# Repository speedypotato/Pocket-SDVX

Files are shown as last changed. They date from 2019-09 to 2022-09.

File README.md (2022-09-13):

# Pocket-SDVX
A mini controller for games such as Sound Voltex, USC, KShoot, osu 4k, etc.  Based off of mon's Pocket Voltex and Cammy's pocketvtx!

Although I won't be selling this particular design anymore, I have plans to sell other miniature controller designs soon.  Join the discord for discussion and support! https://discord.gg/MmuKd73XbY . I also now have a storefront! https://www.speedylabs.us/

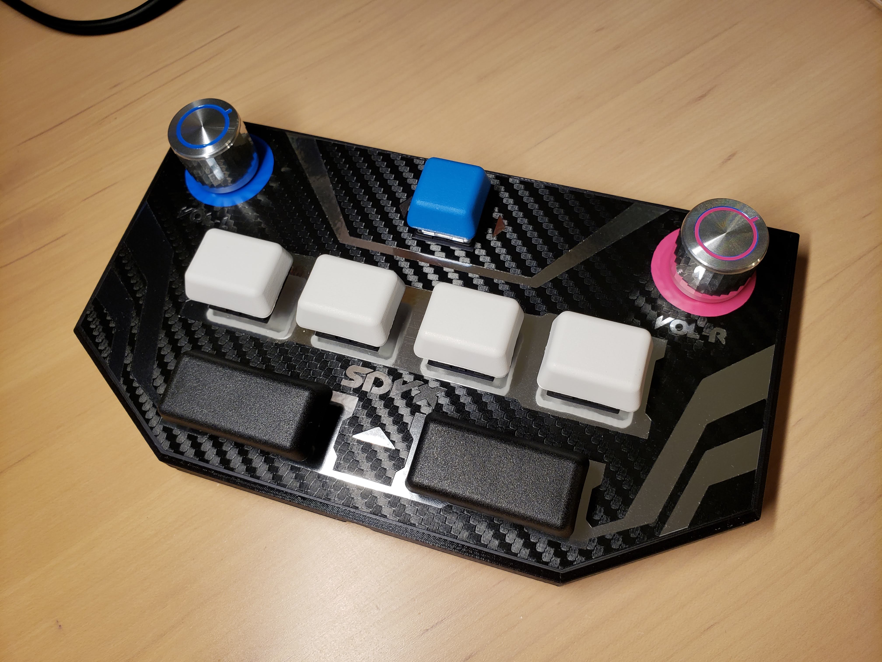
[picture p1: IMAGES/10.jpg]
Pocket SDVX 14


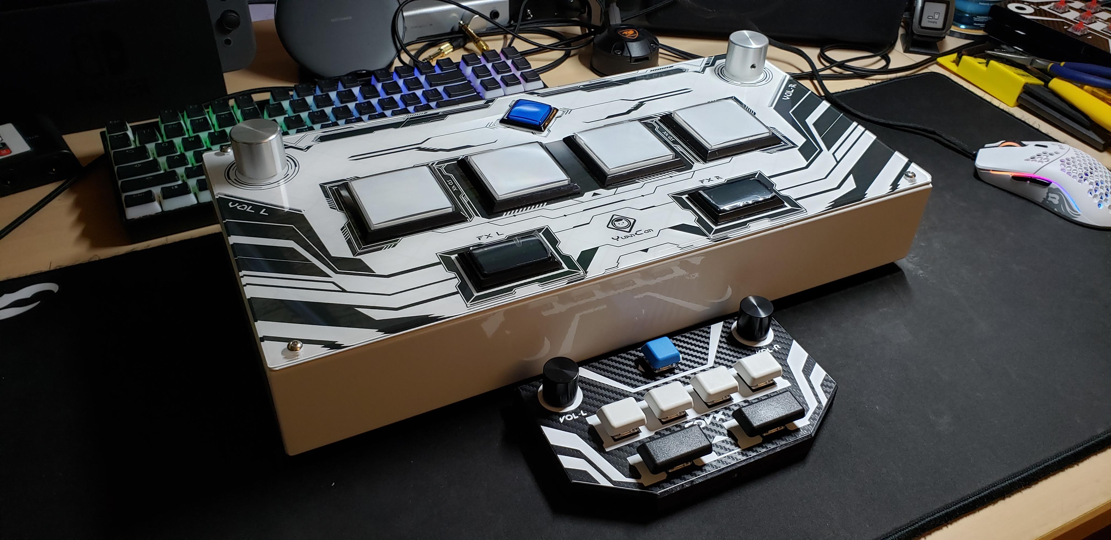
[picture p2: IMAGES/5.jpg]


## Features
- Super small - About 7" x 4" and a little over 1/2" high (About 1-1/2" including knobs)
- 7 Gateron Red Keyswitches (Start, BT-A, BT-B, BT-C, BT-D, FX-L, FX-R)
- Reactive & HID LEDs
- PBT G20 Keycaps
- Quality Bourns Encoders (VOL-L, VOL-R)
- Solid Aluminum Black 20mm Knobs
- Vinyl Skinned Top & Bottom
- 6 Rubber Feet
- Single Screw Back Panel
- Arduino Pro Micro based
- Acts as a gamepad or keyboard/mouse.  While plugging in, hold BTN-A for 3-4s for gamepad mode.  Hold BTN-B instead for keyboard/mouse mode.
- USB-C Input

## Video Guide
- A really low-quality video guide series I made at 4:00am: https://www.youtube.com/playlist?list=PLSlCMOwxujV7-DYrM4eC2Sb4_rMR5udEE .
  - Perhaps it will be useful to some of you.

## Parts Required:
- 1x 3D Printed Case (1.2mm walls, top, bottom layers; 20-25% infill minimum)
- 1x 3D Printed Cover
- 1x layer1 Vinyl Skin [width is ~169mm (scale the skin proportionally)]
- 1x layer2 Vinyl Skin [width is ~169mm (scale the skin proportionally)]
- 1x cover Vinyl Skin [width is ~165mm (scale the skin proportionally)]
- 7x Gateron Red Keyswitches (or other similar MX-style switch)
- 2x Bourns PEC16-2015F-N0024 Encoders
- 1x 1x1 G20 Keycap
- 4x 1x1.25 G20 Keycap
- 2x 1x2 G20 Keycap
- 2x 20mm Diameter Solid Aluminum Knobs (17-22mm height, 6mm inner diameter hole)
- 1x Arduino Pro Micro
- 6x Rubber Feet (0.8-1cm in diameter)
- 1x Micro USB Male to USB C Female (27cm length)
- 1x M3x5 Screw
- Cat5e Cable (~2 feet, strip it open and take a twist of wire)
- Hot Glue
- Solder
- USB C cable (preferably one with deep insertion)

## LED Parts Required:
- 7x 2x3x4mm Square LEDs (choose your desired colors)
- 7x Resistors (High brightness 100Ohm, Medium brightness 220Ohm)

## Recommended Tools/Etc.
- Temperature Controlled Soldering Iron
- Hot Glue Gun
- Needle Nose Pliers
- Wire Cutter/Stripper
- Phillips Screwdriver (if you use a phillips head M3 screw)
- Allen Key (for knobs' grubscrew, M3 screw if you have a hex head)
- Rubbing/Isopropyl Alcohol
- Microfiber Cloth (for cleaning w/ alcohol)
- Eye Protection + Safety Mask

## General Assembly Instructions
- 3D print case and cover.
- Cut vinyls: layer1, layer2, cover_v2.
- Weed vinyls(remove excess).
- Clean face with rubbing/isopropyl alcohol and apply skin using transfer tape.  Apply layer1, then layer2.  Then apply cover.
  - Note: Shine a flashlight on the case's corner to more easily see where to line up the skin.  I make my skins every so slightly smaller than the actual face for more leeway.  The skin's width is ~169mm (scale the skin proportionally).
  - Note 2: Apply to the best of your ability, with even spacing along all sides.  The skin's width is ~165mm (scale the skin proportionally).
- Insert Gateron switches and secure each corner of the switch with hot glue on the inside.  See video Part 1 for details.
- Using a soldering iron, tin all contacts on the Gateron switches.
- Wire up all the common/ground for the switches and the encoders.  See video Part 2 for details.
- Wire up all the switches and encoders with their own individual wire.
- Solder all the wires to the board.  See video Part 3 for details.
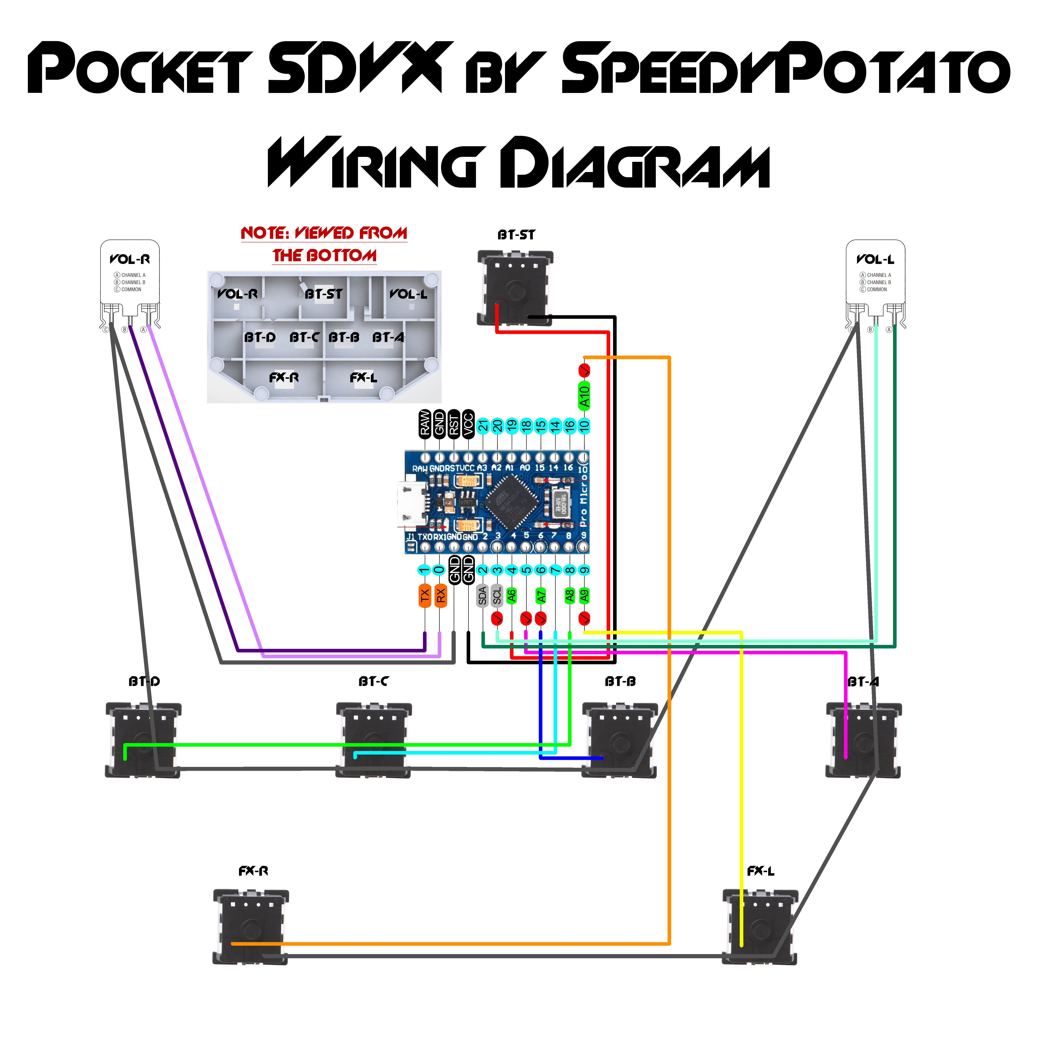
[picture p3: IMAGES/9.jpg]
Pocket SDVX Wiring Diagram
  
  - Arduino Pro Micro Pinout
    - VOL-L A 2
    - VOL-L B 3
    - VOL_R A 0 (RXI)
    - VOL_R B 1 (TXO)
    - BT_ST   4
    - BT_A    5
    - BT_B    6
    - BT_C    7
    - BT_D    8
    - FX_L    9
    - FX_R    10
- Plug in your arduino and flash firmware.  See video Part 4 for details.  Note: If you are running into the "Using OLD HID" error, try enabling verbose compilation output under File > Preferences > Show Verbose Output during [compilation] and uploading again.  For some reason, this fixes it for me most of the time.
- BOOT IN KEYBOARD MODE(Hold the second button from the left for 3-4s while plugging it in).  TEST to make sure everything works.  See video Part 5 for details.
- Plug in micro usb to USB-C adapter cable into the arduino.  Slide arduino into its slot and route the USB-C cable.  See video Part 6 for details.
- Push encoders through their holes.  Mount with washer and nut.
- Bend metal encoder mounting tabs 45 degrees outward.  Additionally, bend one of the protrusions slightly inward so it doesn't collide with the micro usb cable.
- Do some cable management.  Carefully flatten the cables.
- Hot glue USB-C port.
- Slide in the cover and secure with M3x5 screw.  PLEASE be careful, as you are threading into plastic and thus the hole is easily strippable.  See video Part 7 for details.
- Wipe circles on the bottom with rubbing/isopropyl alcohol.  Apply adhesive rubber feet.
- Mount keycaps.  See video Part 8 for details.
- Mount knobs.  Use the arduino pin headers as a spacer on each side so the knobs are the same height and don't rub on the encoder nub.
- Flash firmware and setup your desired game.  See "Pocket SDVX Guide - Flash Firmware & Game Setup" for details.
  - Arduino IDE: https://www.arduino.cc/en/main/software
  - KONAMI SPOOF NO LONGER NEEDED - JUST SELECT "ARDUINO LEONARDO"

## HID LED Assembly Instructions
- Take off keycaps.
- Insert LED through switch.
- Solder negative(shorter) leg to the switch's leg that connects to ground/common.  Clip LED shorter if needed.
- Solder resistor(100 or 220 Ohm depending on desired brightness) to positive(longer) leg.  Clip LED & resistor shorter if needed.
- Solder other end of resistor to a wire.  The other end of the wire will be soldered to the Arduino Pro Micro.
  - Arduino Pro Micro Pinout for LEDs
    - BT_ST_LED 16
    - BT_A_LED  14
    - BT_B_LED  15
    - BT_C_LED  18 (A0)
    - BT_D_LED  19 (A1)
    - FX_L_LED  20 (A2)
    - FX_R_LED  21 (A3)
- Plug in your arduino and flash firmware if it needs to be updated.
- Flatten cables and close cover.
### Done.  Enjoy!!

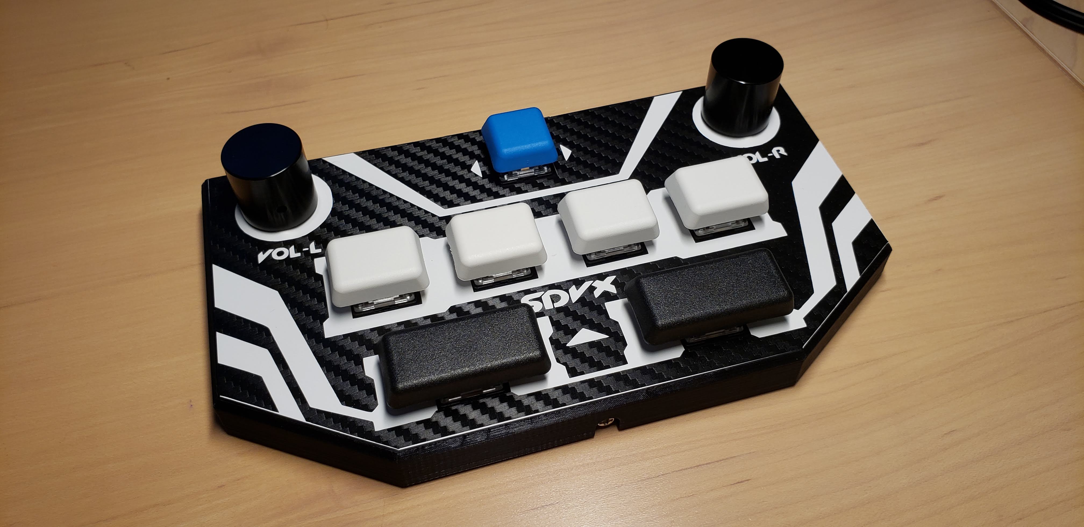
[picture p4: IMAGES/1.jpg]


## Links I used to make the first batch of 10
NOTE: Links dead?  See /IMAGES/screenshots/ for an example of what you are looking for!
- Gateron Red Keyswitches: https://kbdfans.com/collections/gateron-swithes/products/gateron-swtich-3pin-or-5pin?variant=35765199373
- Bourns PEC16-2015F-N0024 Encoders: https://www.mouser.com/ProductDetail/Bourns/PEC16-2015F-N0024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
- 1x1 G20 Keycap (BCT): https://pimpmykeyboard.com/g20-1-space-pack-of-10/
- 1x1.25 G20 Keycap (WAN): https://pimpmykeyboard.com/g20-1-25-space-pack-of-4/
- 1x2 G20 Keycap (NEM): https://pimpmykeyboard.com/g20-2-space-pack-of-4/
- 20mm Diameter Solid Aluminum Knobs: https://www.aliexpress.com/item/32912465745.html?spm=a2g0o.cart.0.0.43bd3c00dwdyAf&mp=1
- Arduino Pro Micro (WARNING: CONTAINS 10): https://www.aliexpress.com/item/4000045084392.html
- Rubber Feet: https://www.ebay.com/itm/50PCS-Rubber-Feet-Clear-Semicircle-Bumpers-Door-Silicone-Buffer-Pad-Furniture/152925672374
- Micro USB Male to USB C Female: https://www.aliexpress.com/item/32983342667.html
- M3x5 Screw: https://www.ebay.com/itm/20X-M3-3-80mm-Round-Pan-Head-Phillips-Screws-304-Stainless-Steel-Machine-Screws/302237442873
- USB C cable (WARNING: CONTAINS 10): https://www.aliexpress.com/item/33032210292.html

## Links I used for LEDs
NOTE: Links dead?  See /IMAGES/screenshots/ for an example of what you are looking for!
- 2x3x4mm LEDs: https://www.aliexpress.com/item/4000463652201.html
- 100Ohm Resistors: https://www.ebay.com/itm/100PCS-1-4W-0-25W-Metal-Film-Resistor-1-Full-Range-of-Values-0%CE%A9-to-10M%CE%A9/252838503547

## Alternate Parts to Consider
- DSA profile keycaps might be a good alternative to G20 if G20 is too expensive or hard to get.
- 20mm knobs can be picked up for much cheaper if you opt for ones that are not all aluminum.
- Can't get Bourns encoders?  Sorry, I have yet to find a good alternative.
- Vinyl skin alternative?  Print out layer2.png on paper, cut it out, and glue it on.  Can also try laminating with packing tape for more durability.
- Cherry MX O-Ring Dampers can be used for a quieter and softer bottom-out.  I had to put 2 on FX-L and FX-R each for dampening to work.  The rest of the keycaps have 1 O-Ring.

## Miscellaneous Info
- The fancy looking knobs I used for Pocket SDVX #14: https://www.amazon.com/gp/product/B07PQ5H6MF/
- I recommend printing the case in a solid dark color so that the pro micro LED doesn't shine through.  Then print the cover in a transparent/white color so that the pro micro LED shines through on the bottom, acting as a neat little power LED.
- If the rubber feet aren't doing their job, they're probably dusty.  Wipe them down with a little bit of rubbing alcohol.
- Encoders have an initial break-in period.  If they are stiff, rotate them for a few minutes to break them in.
- This work is licensed under a Creative Commons Attribution-NonCommercial-ShareAlike 4.0 International License.
Creative Commons

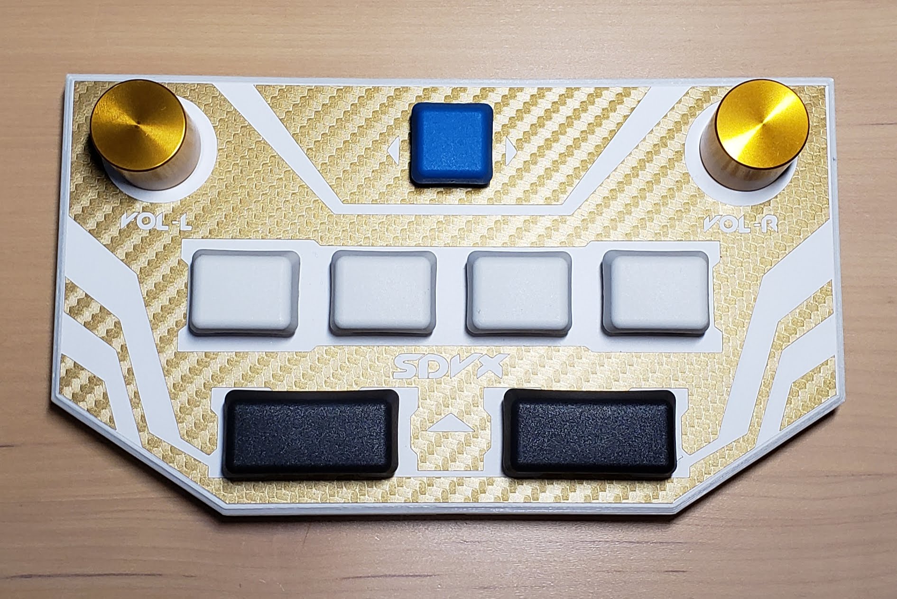
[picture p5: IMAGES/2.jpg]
Gold Pocket SDVX


## Thanks To
- Cammy for helping me build my first minicon.  The Pocket SDVX uses a slightly modified version of his firmware.
- Everyone in the Cons & Stuff Discord channel.
- mon for his initial development of the Pocket Voltex.
- The 10 people who purchased my first exclusive batch of Pocket SDVXs!  Thanks to you guys, I can get a full-size controller as well!
- CrazyRedMachine for HID stuff

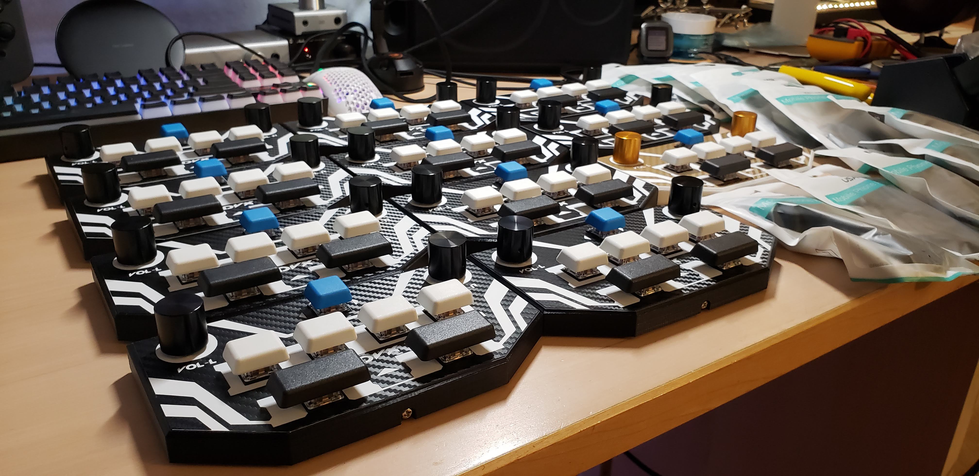
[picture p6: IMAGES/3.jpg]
10 Pocket SDVX


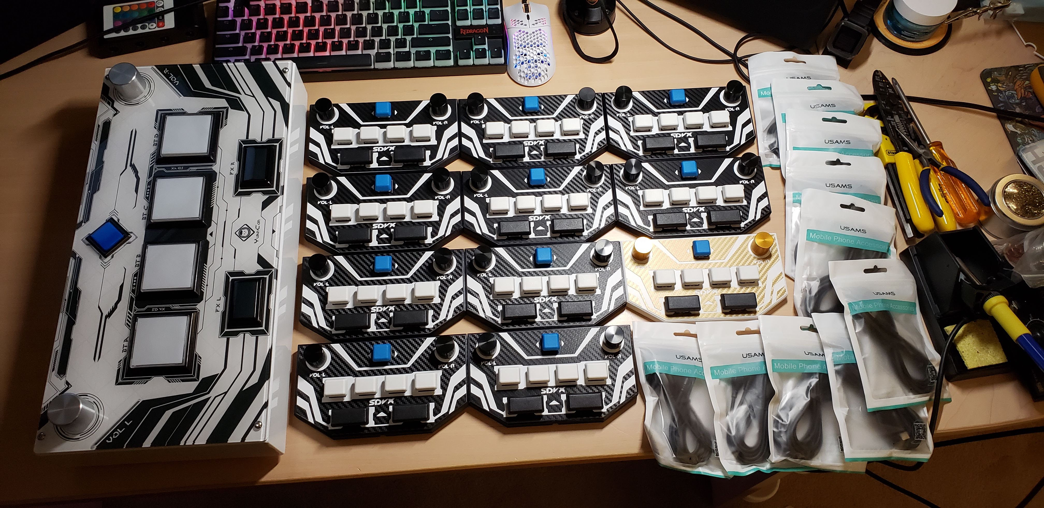
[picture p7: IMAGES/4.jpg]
10 Pocket SDVX 2


## Links to other GitHubs
- https://github.com/camprevail/pocketvtx
- https://github.com/mon/PocketVoltex

## Possible To-Do List
- M3 Nut hole on cover
- Increase spacing between BTN and FX
- Tweak vinyl skin aesthetic button size cutouts
- Consider new way to secure back panel

## Finished Items from the To-Do List
- Konami Spoof compatible
- HID LEDs [See YouTube guide]
- LED lights [See YouTube guide]
- Actually make a cover vinyl that fits right [use cover_v2.png]

## More Pictures
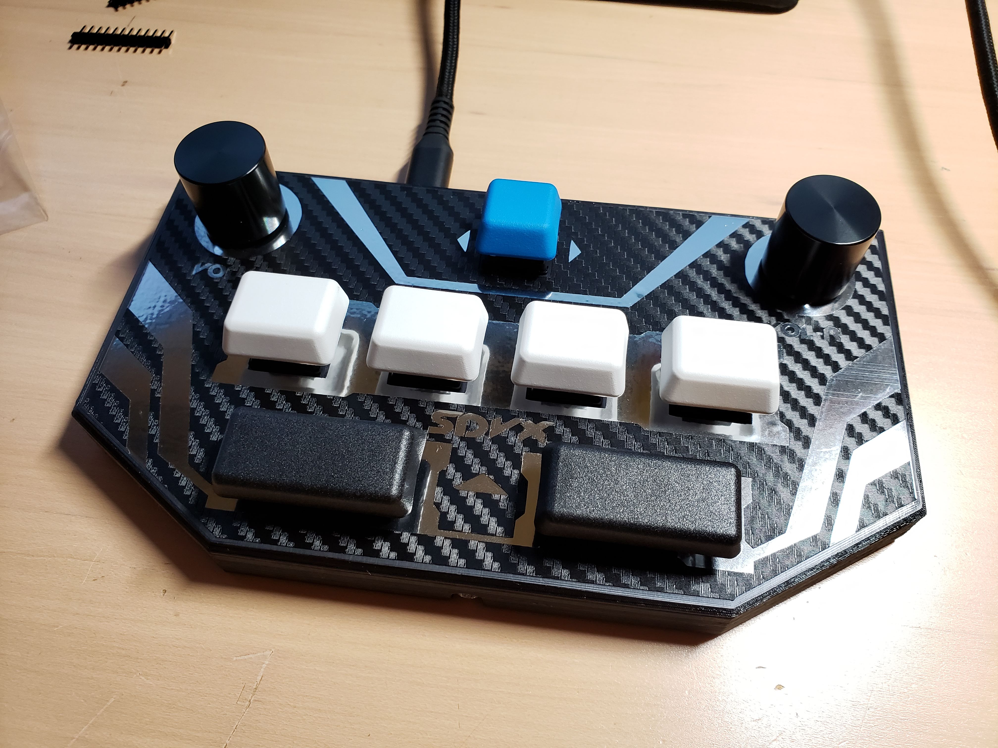
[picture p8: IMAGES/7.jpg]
Pocket SDVX 13


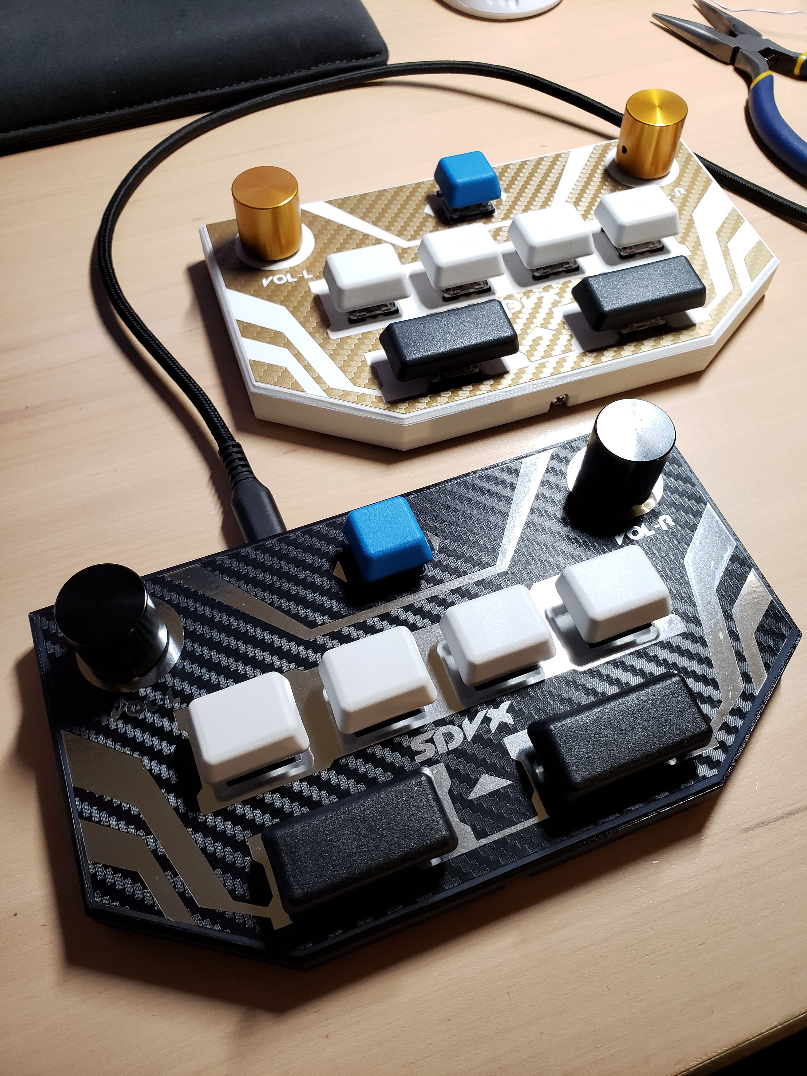
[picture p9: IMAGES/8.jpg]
Pocket SDVX 11 and 13


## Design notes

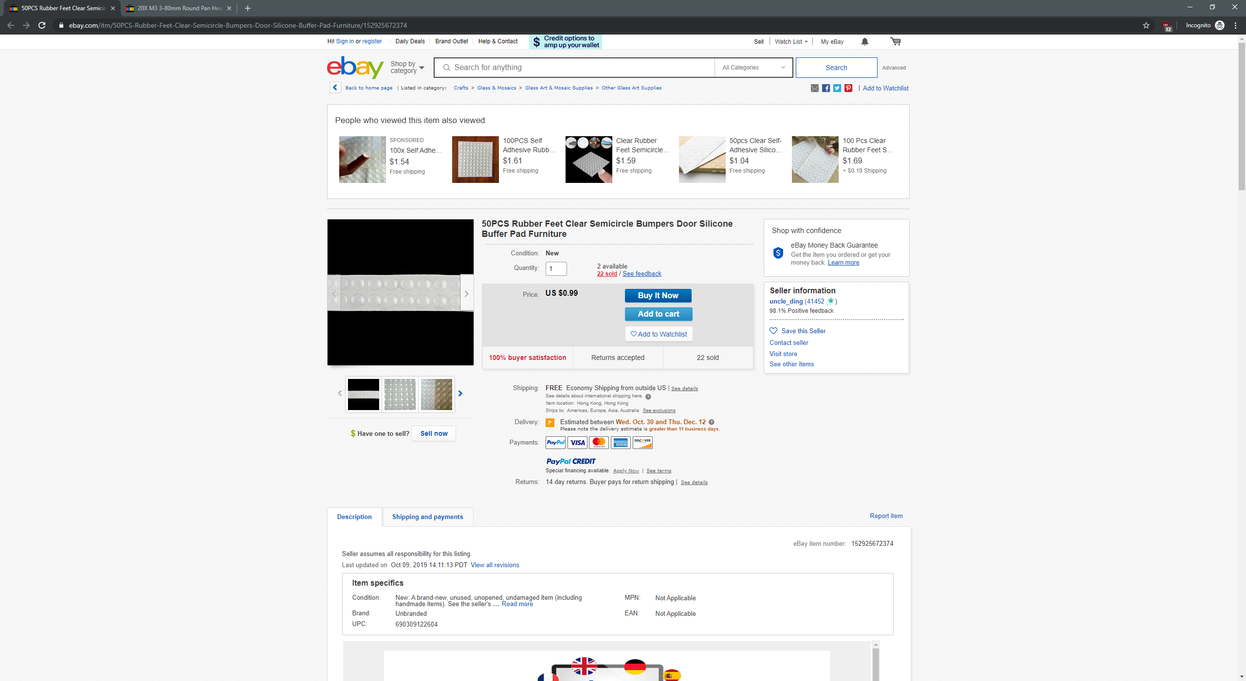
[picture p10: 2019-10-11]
IMAGES/screenshots/feet.png

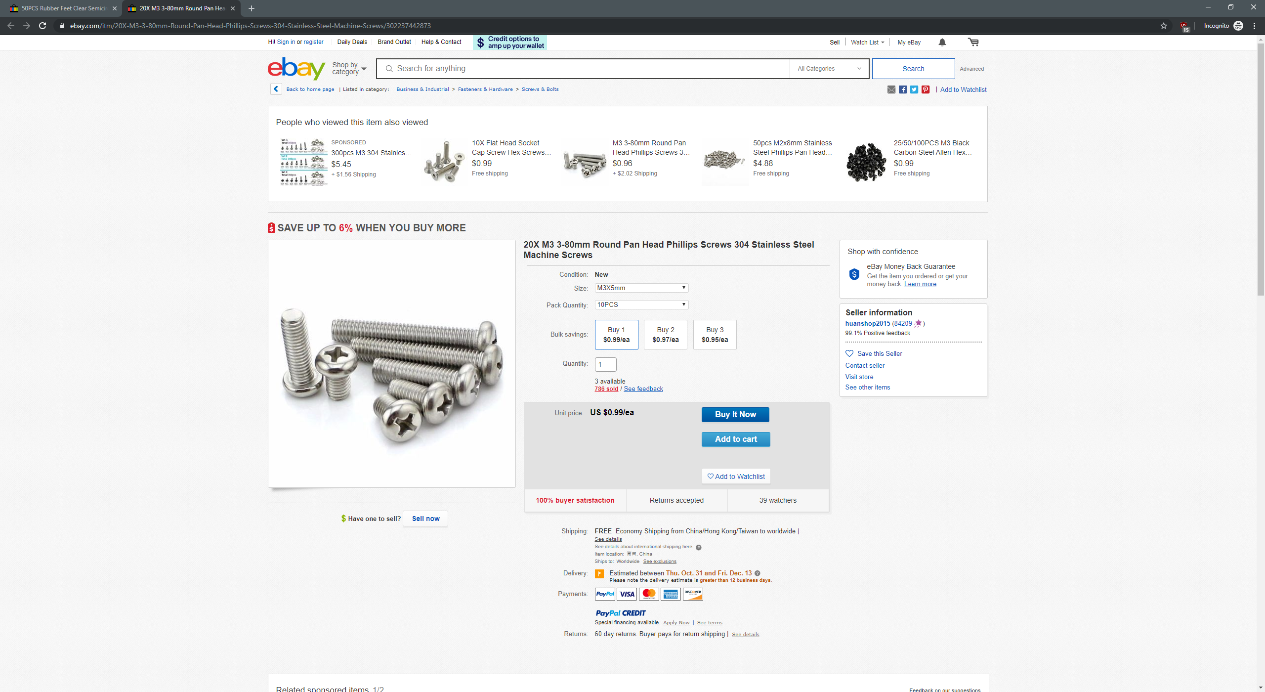
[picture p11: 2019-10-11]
IMAGES/screenshots/screw.png

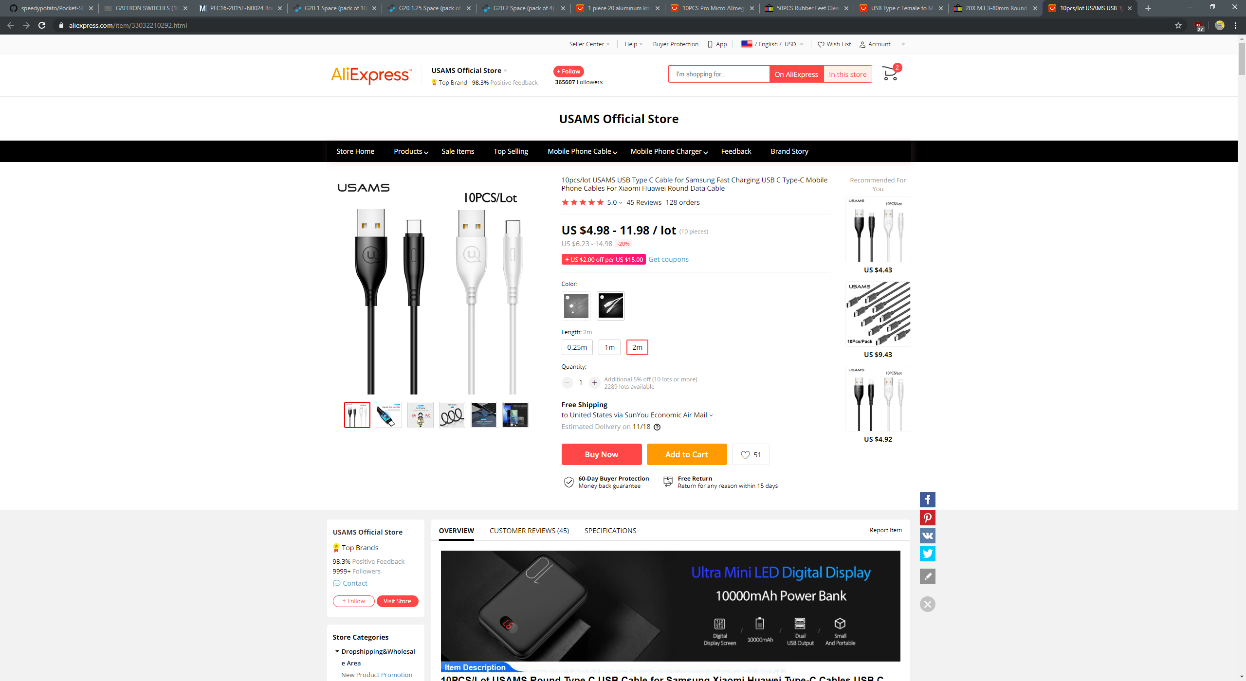
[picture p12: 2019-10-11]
IMAGES/screenshots/usbccable.png

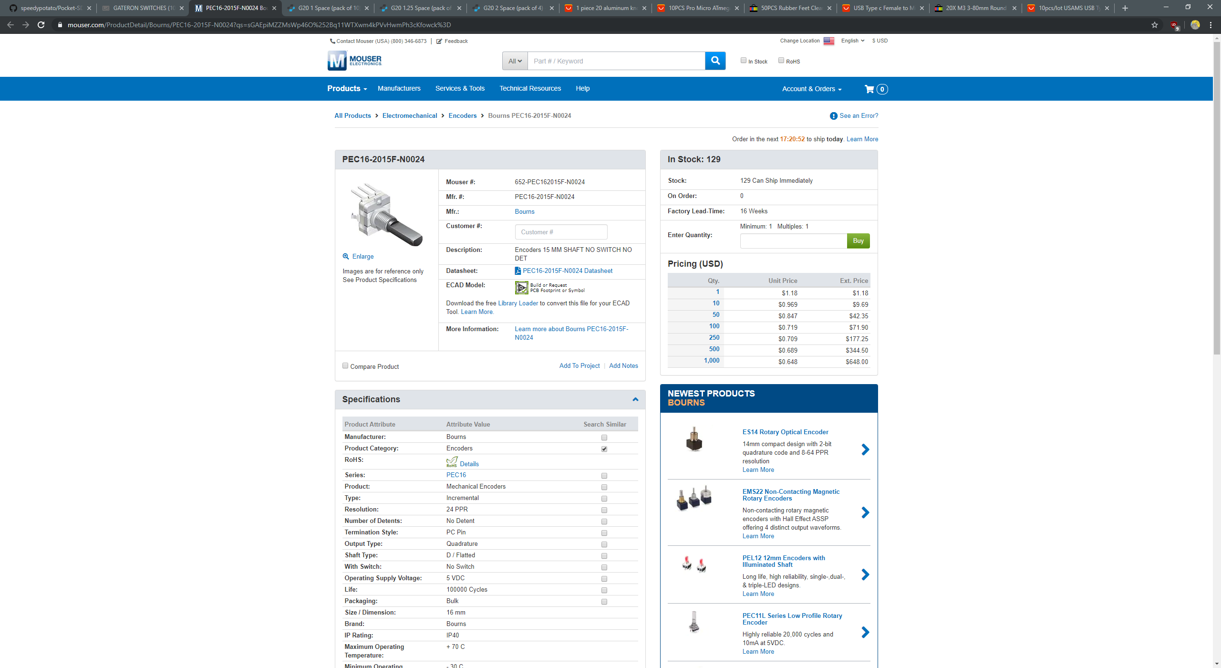
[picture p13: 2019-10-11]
IMAGES/screenshots/encoder.png

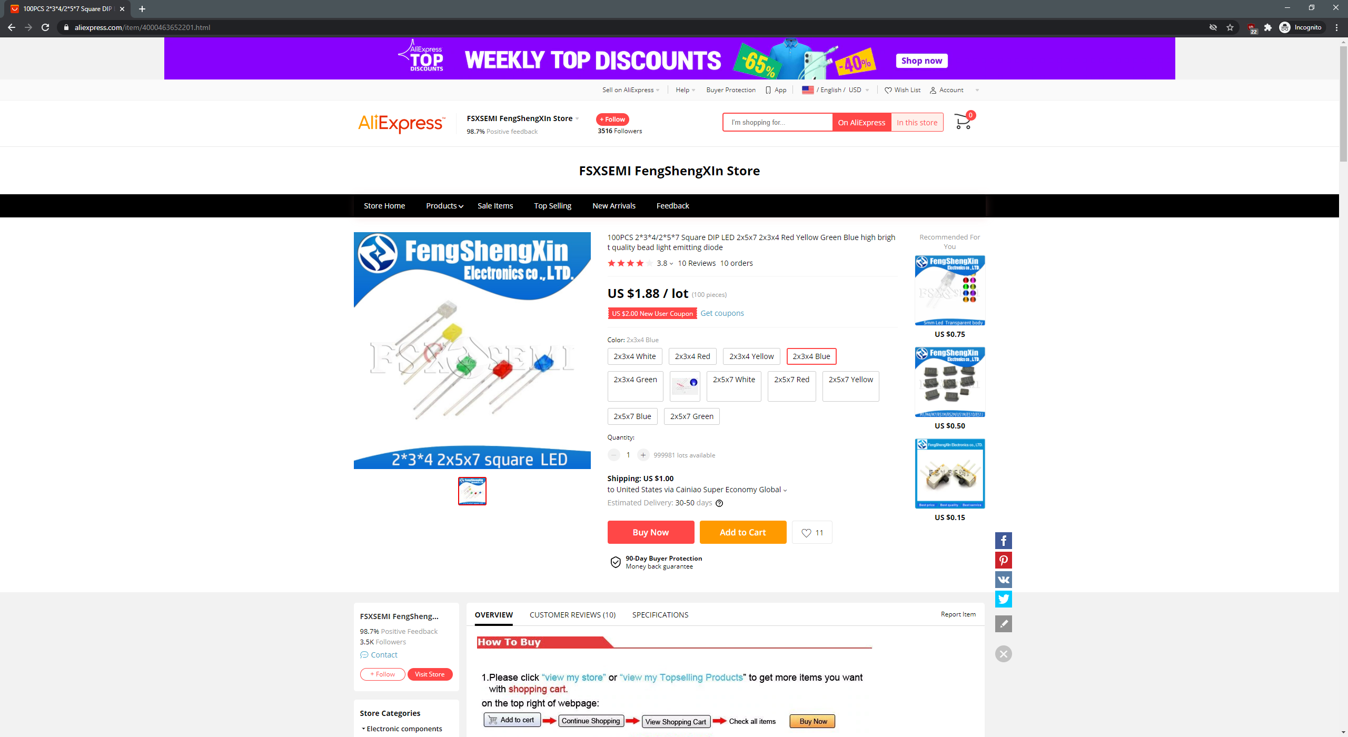
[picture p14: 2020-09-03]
IMAGES/screenshots/2x3x4LED.png

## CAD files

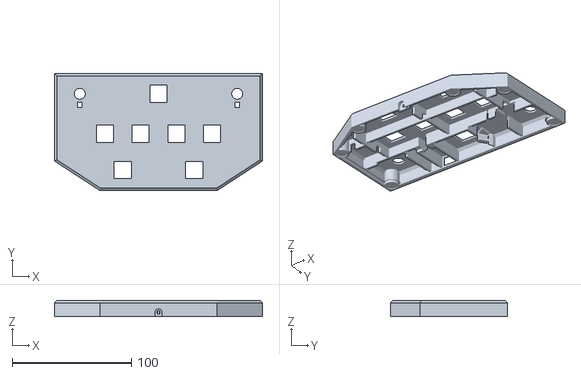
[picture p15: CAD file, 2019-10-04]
STL/case_r2-1.STL
174.7 x 98.5 x 13.5

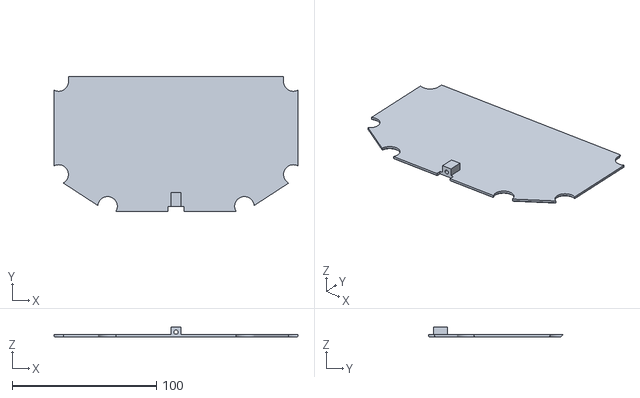
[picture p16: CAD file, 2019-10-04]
STL/cover_r2-1.STL
169.2 x 93.4 x 6.93

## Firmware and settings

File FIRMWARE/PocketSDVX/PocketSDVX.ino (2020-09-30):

#include "iivx_leo.h"
#include "Encoder.h"
iivxReport_t report;
#include "Keyboard.h"
#include "Mouse.h"
#include <EEPROM.h>

// Number of microseconds between HID reports
// 2000 = 500hz
#define REPORT_DELAY 1000

// Read eeprom address 0. Value stored indicated mode. Mode1=joystick, Mode2=keyboard.
int currMode = EEPROM.read(0);

// Mouse Sens Multiplier
#define MOUSE_MULT  3

// Button Keybinds
#define BIND_A    'a'
#define BIND_B    's'
#define BIND_C    'd'
#define BIND_D    'f'
#define BIND_FX_L 'z'
#define BIND_FX_R 'x'
#define BIND_ST   KEY_RETURN

// Button Pinout
#define BT_A  5
#define BT_B  6
#define BT_C  7
#define BT_D  8
#define FX_L  9
#define FX_R  10
#define BT_ST 4

// LED Pinout
#define BT_A_LED  14
#define BT_B_LED  15
#define BT_C_LED  18
#define BT_D_LED  19
#define FX_L_LED  20
#define FX_R_LED  21
#define BT_ST_LED 16

// Number of cycles before HID falls back to reactive
unsigned long reactiveTimeoutMax = 1000;
unsigned long reactiveTimeoutCount = reactiveTimeoutMax;

uint8_t bindKeys[] = { BIND_A, BIND_B, BIND_C, BIND_D, BIND_FX_L, BIND_FX_R, BIND_ST };
uint8_t buttonPins[] = { BT_A, BT_B, BT_C, BT_D, FX_L, FX_R, BT_ST };
uint8_t ledPins[] = { BT_A_LED, BT_B_LED, BT_C_LED, BT_D_LED, FX_L_LED, FX_R_LED, BT_ST_LED };
uint8_t buttonCount = sizeof(buttonPins) / sizeof(buttonPins[0]);

// Encoder sensitivity = number of positions per rotation times 4 (24*4) / number of positions for HID report (256)
#define ENCODER_SENSITIVITY (double) 0.375
Encoder encL(3, 2), encR(1, 0);
float knob1 = 0;
float knob2 = 0;
float old_knob1 = 0;
float old_knob2 = 0;

/**
 * Light Logic for Controller & HID Mode
 * @param lightDesc Bit representation of activated lights
 */
void lights(uint16_t lightDesc) {
  for (int i = 0; i < buttonCount - 1; i++) {
    if ((lightDesc >> i) & 1) {
      digitalWrite(ledPins[i], HIGH);
    } else {
      digitalWrite(ledPins[i], LOW);
    }
  }
  // Start button light: 8 for controller reactive, 6 for HID
  if ((lightDesc >> 8) & 1 || (lightDesc >> 6) & 1) {
    digitalWrite(BT_ST_LED, HIGH);
  } else {
    digitalWrite(BT_ST_LED, LOW);
  }
}

/**
 * Arduino Setup
 */
void setup() {
  // Setup I/O for pins
  for (int i = 0; i < buttonCount; i++) {
    pinMode(buttonPins[i], INPUT_PULLUP);
    pinMode(ledPins[i], OUTPUT);
  }

  // Startup mode
  int Button1State = digitalRead(BT_A); //Read Btn-A
  int Button2State = digitalRead(BT_B); //Read Btn-B
  // Button 1 is held down: Joystick Mode
  if (Button1State == LOW && Button2State == HIGH) {
    if (currMode != 1) {
      EEPROM.update(0, 1); 
      delay(200);
    }
  } else if (Button2State == LOW && Button1State == HIGH) {
    // Button 2 is held down: Keyboard Mode
    if (currMode != 2) {
      EEPROM.update(0, 2);
      delay(200);
    }
  }
}

/**
 * Arduino Loop
 */
void loop() {
  if (EEPROM.read(0) == 1) {
    joy_mode();
  } else if (EEPROM.read(0) == 2) {
    keyboard_mode();
  }
}

/**
 * Keyboard Implementation
 */
void keyboard_mode() {
  // Read encoders
  knob1 =  (float)(encL.read());
  knob2 = (float)encR.read();

  if(knob1 != old_knob1) {
    Mouse.move((knob1 - old_knob1) * MOUSE_MULT, 0);
    
    // We count the difference in the encoders, but we must not go over arduino's int limit
    if(knob1 < -255 || knob1 > 255) {
      encL.write(0);
      old_knob1 = 0;
    } else {
      old_knob1 = knob1;
    }
  }
  
  if(knob2 != old_knob2) {
    Mouse.move(0, (knob2 - old_knob2) * MOUSE_MULT);
    
    if(knob2 < -255 || knob2 > 255) {
      encR.write(0);
      old_knob2 = 0;
    } else {
      old_knob2 = knob2;
    }
  }
  
  // Read the buttons, if it's low, output a keyboard press  
  for (int i = 0; i < buttonCount; i++) {
    if (digitalRead(buttonPins[i]) == LOW) {
      Keyboard.press(bindKeys[i]);
      digitalWrite(ledPins[i], HIGH);
    } else {
      Keyboard.release(bindKeys[i]);
      digitalWrite(ledPins[i], LOW);
    }
  }
}

/**
 * Controller Implementation
 */
void joy_mode() {
  // Read buttons except BT_ST
  for (int i = 0; i < buttonCount - 1; i++) {
    if (digitalRead(buttonPins[i]) != HIGH) {
      report.buttons |= (uint16_t)1 << i;
    } else {
      report.buttons &= ~((uint16_t)1 << i);
    }
  }
  // Read BT_ST
  if (digitalRead(BT_ST) != HIGH) {
    report.buttons |= (uint16_t)1 << 8;
  } else {
    report.buttons &= ~((uint16_t)1 << 8);
  }
  
  // Read Encoders
  report.xAxis = (uint8_t)((int32_t)(encL.read() / ENCODER_SENSITIVITY) % 256);
  report.yAxis = (uint8_t)((int32_t)(encR.read() / ENCODER_SENSITIVITY) % 256);
  
  // Reactive or HID LED switching
  if (reactiveTimeoutCount >= reactiveTimeoutMax) {
    lights(report.buttons);
  } else {
    reactiveTimeoutCount++;
    lights(iivx_led);
  }
  
  iivx.setState(&report);
  delayMicroseconds(REPORT_DELAY);
}

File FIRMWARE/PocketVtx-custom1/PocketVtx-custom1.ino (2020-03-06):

#include "iivx_leo.h"
#include "Encoder.h"
iivxReport_t report;
#include "Keyboard.h"
#include "Mouse.h"
#include <EEPROM.h>

// Number of microseconds between HID reports
// 2000 = 500hz
#define REPORT_DELAY 2000

int currMode = EEPROM.read(0); // Read eeprom address 0. Value stored indicated mode. Mode1=joystick, Mode2=keyboard.
uint8_t buttonCount = 7;

// Button Keybinds
#define BIND_ST   KEY_RETURN
#define BIND_A    'a'
#define BIND_B    's'
#define BIND_C    'd'
#define BIND_D    'f'
#define BIND_FX_L 'z'
#define BIND_FX_R 'x'

// Button Pinout
#define BT_ST 4
#define BT_A  5
#define BT_B  6
#define BT_C  7
#define BT_D  8
#define FX_L  9
#define FX_R  10

// 0 = reactive lighting, 1 = HID lighting
uint8_t lightMode = 0;

uint8_t buttonPins[] = { 4, 5, 6, 7, 8, 9, 10};
uint8_t ledPins[] = {15, 15, 15, 15, 15, 15, 15, 15, 15};

// encoder sensitivity = number of positions per rotation times 4 (24*4) / number of positions for HID report (256)
#define ENCODER_SENSITIVITY (double) 0.375
Encoder encL(3, 2), encR(1, 0);
float knob1 = 0;
float knob2 = 0;
float old_knob1 = 0;
float old_knob2 = 0;

void lights(uint8_t lightDesc) {
  for (int i = 0; i < buttonCount; i++) {
    if ((lightDesc >> i) & 1) {
      digitalWrite(ledPins[i], HIGH);
    } else {
      digitalWrite(ledPins[i], LOW);
    }
  }
}

void setup() {
  delay(1000);
  
  // Setup I/O for pins
  for (int i = 0; i < buttonCount; i++) {
    pinMode(buttonPins[i], INPUT_PULLUP);
    pinMode(ledPins[i], OUTPUT);
  }

  // startup mode
  int Button1State = digitalRead(5); //Read Btn-A
  int Button2State = digitalRead(6); //Read Btn-B
    // button 1 is held down: Joystick Mode
    if (Button1State == LOW && Button2State == HIGH) {
      if (currMode != 1) { //if eeprom=2
        EEPROM.update(0, 1); 
        delay(200);
      }
    } else if (Button2State == LOW && Button1State == HIGH) {
      // button 2 is held down: Keyboard Mode
      if (currMode != 2) { //if eeprom=1
        EEPROM.update(0, 2);
        delay(200);
      }
    }
}

void loop() {
  if (EEPROM.read(0) == 1) {
    joy_mode();
  } else if (EEPROM.read(0) == 2) {
    keyboard_mode();
  }
}

void keyboard_mode() {
  // read encoders
  knob1 =  (float)(encL.read());
  knob2 = (float)encR.read();

  if(knob1 != old_knob1) {
    // if there's a difference in encoder movement from last pass, move the mouse
    if(knob1 < old_knob1) {
      Mouse.move(-5, 0);
    } else {
      Mouse.move(5, 0);
    }
    
    // we count the difference in the encoders, but we must not go over arduino's int limit
    if(knob1 < -255) {
      encL.write(0);
      old_knob1 = 0;
    } else if (knob1 > 255) {
      encL.write(0);
      old_knob1 = 0;
    } else {
      old_knob1 = knob1;
    }
  }
  
  if(knob2 != old_knob2) {
    if(knob2 > old_knob2) {
      Mouse.move(0, 5);
    } else {
      Mouse.move(0, -5);
    }
    
    if(knob2 < -255) {
      encR.write(0);
      old_knob2 = 0;
    } else if(knob2 > 255) {
      encR.write(0);
      old_knob2 = 0;
    } else {
      old_knob2 = knob2;
    }
  }
  
  // read the buttons for low, if it's low, output a keyboard press  
  if(digitalRead(BT_A) == LOW) {
    Keyboard.press(BIND_A);
  } else {
    Keyboard.release(BIND_A);
  }
  
  if(digitalRead(BT_B) == LOW) {
    Keyboard.press(BIND_B);
  } else {
    Keyboard.release(BIND_B);
  }
  
  if(digitalRead(BT_C) == LOW) {
    Keyboard.press(BIND_C);
  } else {
    Keyboard.release(BIND_C);
  }
  
  if(digitalRead(BT_D) == LOW) {
    Keyboard.press(BIND_D);
  } else {
    Keyboard.release(BIND_D);
  }
  
  if(digitalRead(FX_L) == LOW) {
    Keyboard.press(BIND_FX_L);
  } else {
    Keyboard.release(BIND_FX_L);
  }
  
  if(digitalRead(FX_R) == LOW) {
    Keyboard.press(BIND_FX_R);
  } else {
    Keyboard.release(BIND_FX_R);
  }
  
  if(digitalRead(BT_ST) == LOW) {
    Keyboard.press(BIND_ST);
  } else {
    Keyboard.release(BIND_ST);
  }
}

void joy_mode() {
  // Read buttons
  for (int i = 0; i < buttonCount; i++) {
    if (digitalRead(buttonPins[i]) != HIGH) {
      report.buttons |= (uint16_t)1 << i;
    } else {
      report.buttons &= ~((uint16_t)1 << i);
    }
  }
  // Read Encoders
  report.xAxis = (uint8_t)((int32_t)(encL.read() / ENCODER_SENSITIVITY) % 256);
  report.yAxis = (uint8_t)((int32_t)(encR.read() / ENCODER_SENSITIVITY) % 256);
  // Light LEDs
  if (lightMode == 0) {
    lights(report.buttons);
  } else {
    lights(iivx_led);
  }

/* 
   ------- KEYBOARD ASCII CODES -------
  Top row keys: (use these if you don't have a numpad on your pc)
  48 - 0
  49 - 1
  50 - 2
  51 - 3
  52 - 4
  53 - 5
  54 - 6
  55 - 7
  56 - 8
  57 - 9
  45 - - (minus)(default service button)
  61 - = (equals)(default test button)
  8 - backspace
  
  
  220 NumPad /
  221 NumPad *
  222 NumPad -
  223 NumPad +
  224 NumPad ENTER
  225 NumPad 1 and End
  226 NumPad 2 and Down Arrow
  227 NumPad 3 and PageDn
  228 NumPad 4 and Left Arrow
  229 NumPad 5
  230 NumPad 6 and Right Arrow
  231 NumPad 7 and Home
  232 NumPad 8 and Up Arrow
  233 NumPad 9 and PageUp
  234 NumPad 0 and Insert
  235 NumPad . and Delete
  */
  
  iivx.setState(&report);
  delayMicroseconds(REPORT_DELAY);
}

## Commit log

2019-09-30 Instructions, BOM, Tools, Links, Thanks added
2019-10-04 STL files for case released
    [case_r2-1.STL, cover_r2-1.STL]
2020-06-25 Added wiring diagram + controller #14
2020-06-25 added wiring diagram and controller #14 pictures
2020-07-10 Encoder acceleration in mouse mode, minor refactor
2020-09-30 Reassigned buttons to match konami sdvx, removed startup delay, removed z axis
2020-09-30 WIP removed 2 unused LEDs, removed zAxis decl
2020-09-30 7 HID LEDs, keyboard mode refactor, comments
